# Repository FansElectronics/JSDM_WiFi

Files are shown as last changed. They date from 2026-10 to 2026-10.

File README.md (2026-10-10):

# Jadwal Sholat Dot Matrix (JSDM) P10 dengan ESP8266 & ESP32

Firmware display Jadwal Waktu Sholat dengan tampilan Panel P10 Dot Matrix Display (DMD) menggunakan mikrokontroler ESP8266 dan ESP32. Project ini dirancang untuk menjalankan sebuah sistem dan perhitungan jadwal sholat di Indonesia. Sudah didukung dengan pengaturan dengan aplikasi Android yang dapat di download di: https://play.google.com/store/apps/details?id=com.fanselectronics.jsdm&hl=id

## Spesifikasi Firmware ⚙️:
- Mendukung Mikrokontroler ESP8266 dan ESP32
- Mendukung RTC DS3231
- Mendukung Panel P10 Single Color
- Menggunakan catu daya 5V (disesuaikan panel)
- Pengaturan melalui aplikasi Android
- 1 baris Panel x Maksimal 6 kolom Panel (disesuaikan lisensi)

## Fitur yang tersedia ✅:
- Animasi Jadwal Waktu Sholat (tersida beberapa model animasi sesuai pilihan jumlah panel)
- Animasi pesan running text (custom melalui aplikasi android)
- Logo Allah & Muhammad (tersida beberapa model logo)
- Sleep Mode saat malam hari tidak terpakai
- Kalendar Masehi, Hijriah, dan Jawa (Pasaran, Wuku, dan Tahun menurut kalendar Agungan)
- Alarm / Alert waktu Adzan
- Waktu hitung mundur Qobliyah setelah Adzan dan tunggu Iqomah
- Pengaturan waktu Iqomah setiap sholat
- Sleep Mode waktu sholat
- Sleep Mode waktu khotbah Jum'at
- Upload **license.json** melalui aplikasi android
- Update firmware On the Air (OTA), update firmware lebih mudah via internet

_**Catatan:** fitur dan animasi akan selalu diupdate, anda bisa update firmware terbaru dengan mudah melalui fitur OTA di aplikasi android._

## Default SSID + Password
```
    SSID: JSDM WiFi Android
    PASS: fanselectronics
```

## Mengapa dimulai dari versi 3?

Sebelumnya project ini bersifat private saja dengan membuka firmware dan mengimplementasikan sistem lisensi, siapapun dapat membuat sendiri dan hanya tinggal membeli lisensi firmwarenya saja dengan mudah dan murah.

## Bagaimana Sistem Lisensinya?

Kami mengimplementasikan sistem lisensi terenkripsi berbasis **Identifikasi Hardware** unik. Setiap ESP8266 dan ESP32 memiliki ID Unik yang tidak dapat ditukarkan, jadi pembeli tinggal mengirimkan **Device ID** yang tersedia pada menu activation aplikasi setelah aplikasi terhubung ke perangkat dan kami akan mengirimkan file **license.json** yang dapat diupload ke perangkat melalui fitur **Activation** di aplikasi Android.

Menengapa lisensi harus berbayar? tentunya kami membutuhkan dana untuk keperluan riset dan biaya hidup, permintaan ini juga memberikan kami semangat untuk terus memelihara dan perbarui fitur-fitur pada firmware dari JSDM WiFi Android ini. Sehingga mohon pengertiannya.

**Adapun Harga Lisensi dibedakan berdasarkan jumlah panel sebagai berikut 🏷️:**
- 1 Panel : Rp. 25.000
- 2 Panel : Rp. 35.000
- 3 Panel : Rp. 45.000
- 4 Panel : Rp. 55.000
- 5 Panel : Rp. 65.000
- 6 Panel : Rp. 75.000

**Syarat dan Ketentuan Lisensi 📜:** 
- Lisensi berlaku untuk 1 chip ESP866 atau ESP32, karena mengikat berdasarkan chip.
- Lisensi berlaku untuk 1 jenis jumlah panel (setelah lisensi dikirim tidak bisa ganti ukuran)
- Apabila terjadi kerusakan chip kami bisa mengganti lisensi dengan syarat mengirim chip yang rusak kepada kami guna mengihindari penipuan chip rusak. Kami akan kirim lisensi baru dengan DEVICE ID chip yang baru. kalau tidak bisa mengirimkan chip yang rusak bisa beli lisensi baru kembali.
- Kami tidak menerima garansi lisensi apabila pembelian tidak melalui kami secara langsung (beli di pihak ke-3).

## Sistem pembayaran 💵

Kami memberikan 2 sistem pembayaran dimana sistem donasi dan pembayaran sesuai harga tertera. Anda dapat menggunakan sistem donasi apabila ingin memberikan support kepada kami melebihi harga lisensi yang ada.
- Pembelian dan Bantuan: https://wa.me/6281803750001
- Donasi: https://saweria.co/fanselectronics

## Bagaimana Upload Firmwarenya❓
Kami telah menyediakan tool untuk upload / flash chip ES8266 dan ESP32 yang memudahkan siapapun untuk membuat project ini secara mandiri. Berikut url tool JSDM WiFi Flasher:
- Flasher Tools: https://app.fanselectronics.com/flasher/JSDM/
- Tutorialnya bisa baca di [FLASHER.md](FLASHER.md)

## Skematik dan PCB 💾
Semua file Skematik dan PCB saya sediakan gratis di dalam repository ini dalam bentuk desain apliksi EAGLE PCB hingga export PDF. Sesuaikan dengan board yang anda gunakan atau anda bisa mengkustomisasi sesuai dengan keinginan anda dengan panduan pin I/O yang sudah disediakan.

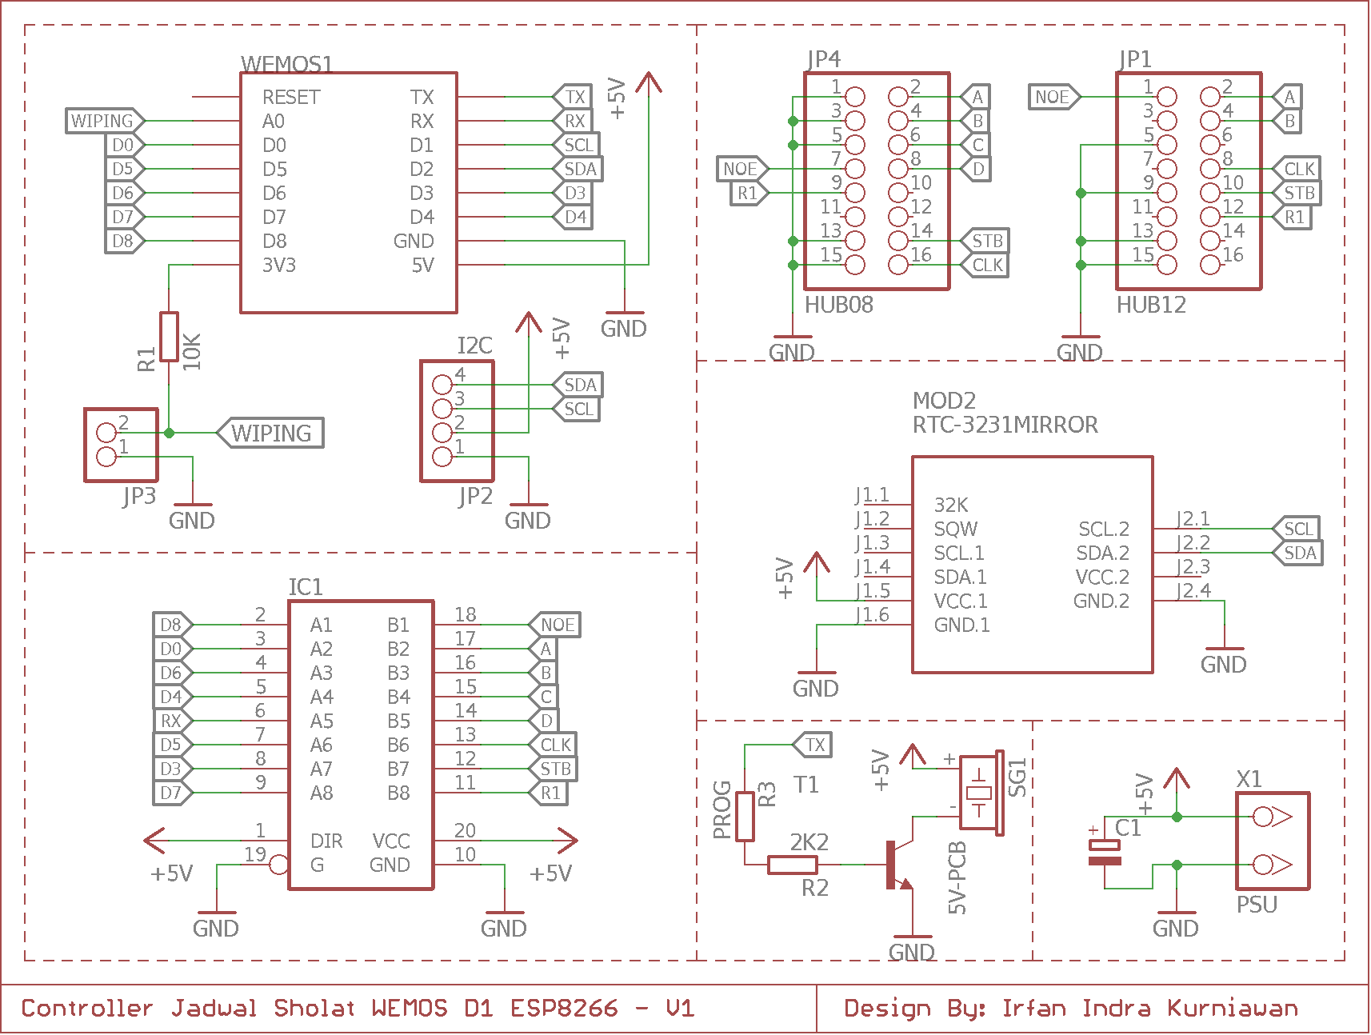
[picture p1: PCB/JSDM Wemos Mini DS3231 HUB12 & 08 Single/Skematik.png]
Skematik JSDM ESP8266 Wemos D1 Mini

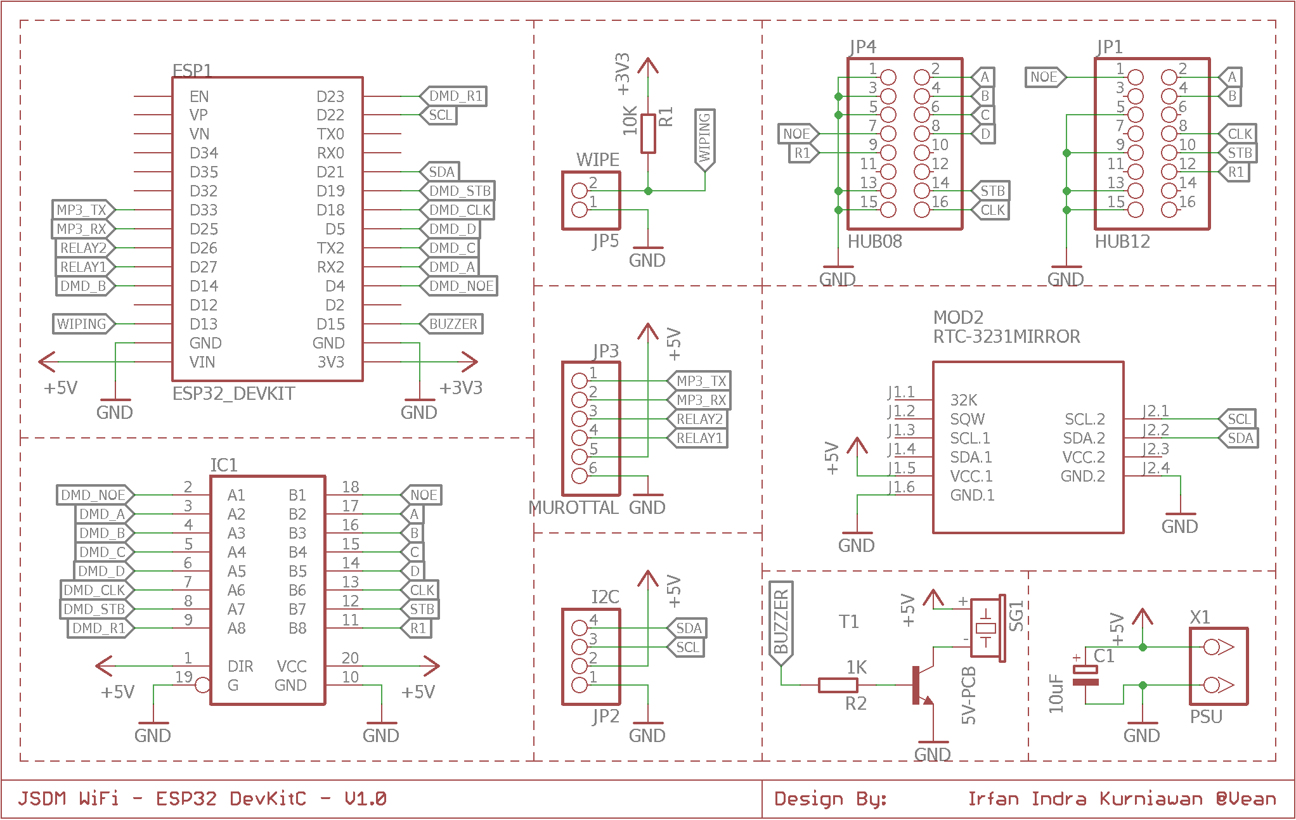
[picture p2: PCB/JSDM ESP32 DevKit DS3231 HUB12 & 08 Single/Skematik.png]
Skematik JSDM ESP32 DevKit


## Tutorial & Video 🎥

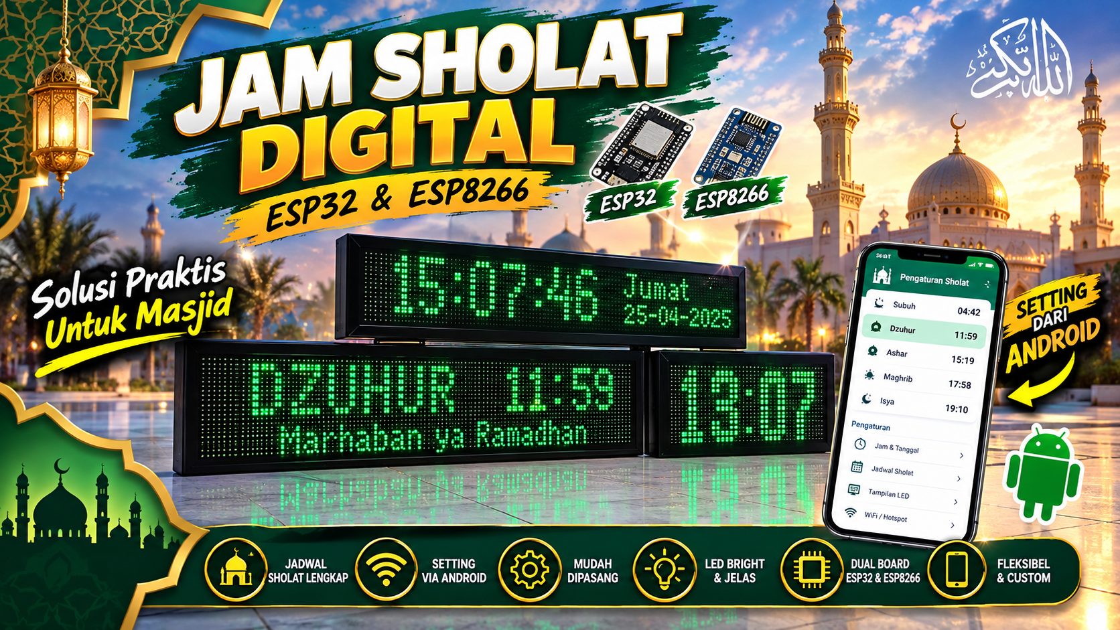
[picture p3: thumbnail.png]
Tutorial JSDM WiFi (https://www.youtube.com/watch?v=nER4bm2BxC0)


## Terima Kasih Kepada 🤲
- Allah Subhanahu Wa Ta'ala
- Arduino.cc
- GitHub
- Kontributor
- Semua orang yang mentraktir saya kopi

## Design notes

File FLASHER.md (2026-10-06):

# Panduan Singkat Flash ESP32 & ESP8266

Gunakan **Google Chrome** atau **Microsoft Edge**.

## Langkah Flashing

1. **Colokkan ESP** ke komputer menggunakan kabel USB Data.

2. Buka ESP Flasher:
   **https://app.fanselectronics.com/flasher/JSDM/**

3. **Masuk ke mode flash:**

   * **ESP32:** tekan dan tahan tombol **BOOT**.
   * **ESP8266:** tekan dan tahan tombol **FLASH**. Jika perlu, tekan **RESET/RST** sekali.

4. Klik **Connect** pada ESP Flasher.

5. Pilih **Serial Port** ESP yang terhubung, lalu klik **Connect**.

6. Setelah ESP berhasil terdeteksi, **lepaskan tombol BOOT/FLASH**.

7. Pilih firmware yang sesuai dengan board:

   * ESP32 → firmware ESP32
   * ESP8266 → firmware ESP8266

8. Jika diperlukan, klik **Erase Flash** dan tunggu sampai selesai.

9. Klik **Flash** untuk memulai proses flashing.

10. **Jangan mencabut USB atau menekan tombol RESET selama proses flashing.** Tunggu sampai proses selesai.

11. Setelah selesai, ESP akan restart dan menjalankan firmware yang baru.

### Jika Gagal Terhubung

Coba ulangi proses dari awal:

**Cabut USB → colok kembali → tahan BOOT/FLASH → Connect → pilih Serial Port → tunggu terdeteksi → lepaskan BOOT/FLASH → Flash.**

Pastikan menggunakan kabel USB **Data** dan browser **Chrome/Edge**.

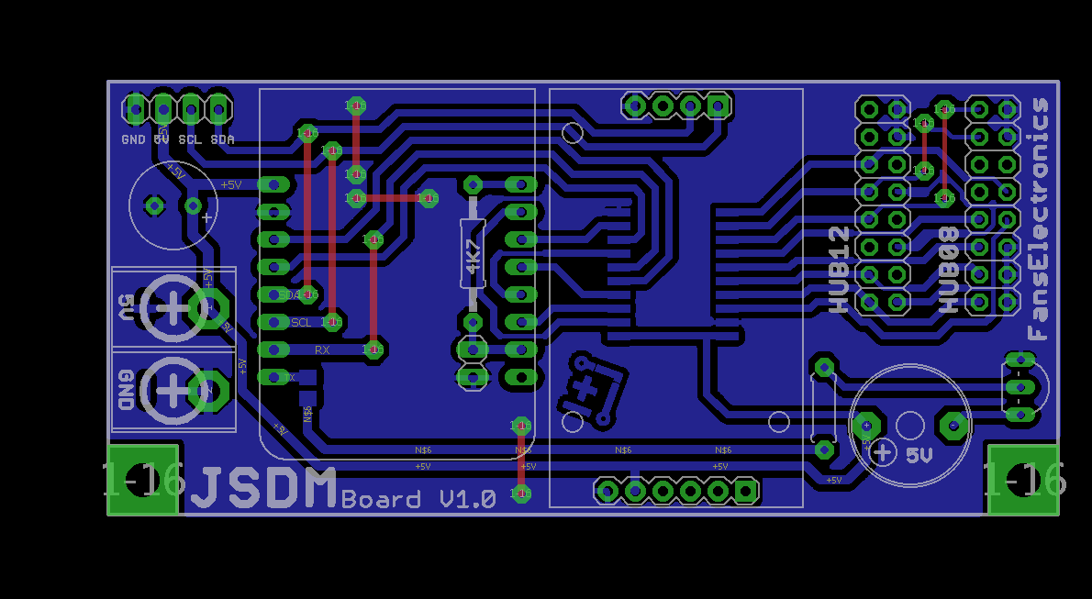
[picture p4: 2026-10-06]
PCB/JSDM Wemos Mini DS3231 HUB12 & 08 Single/Board.png

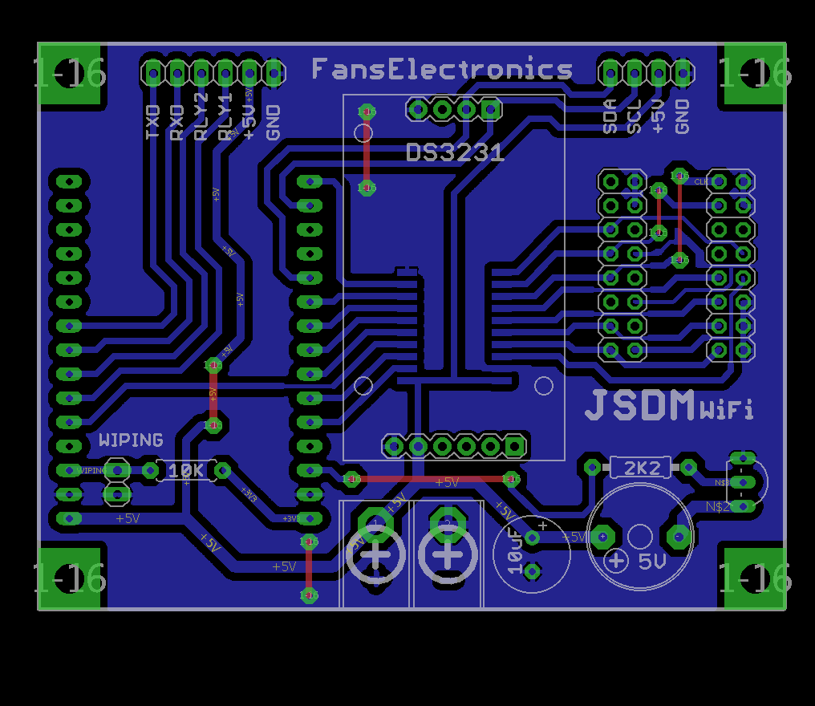
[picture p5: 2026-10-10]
PCB/JSDM ESP32 DevKit DS3231 HUB12 & 08 Single/Board.png

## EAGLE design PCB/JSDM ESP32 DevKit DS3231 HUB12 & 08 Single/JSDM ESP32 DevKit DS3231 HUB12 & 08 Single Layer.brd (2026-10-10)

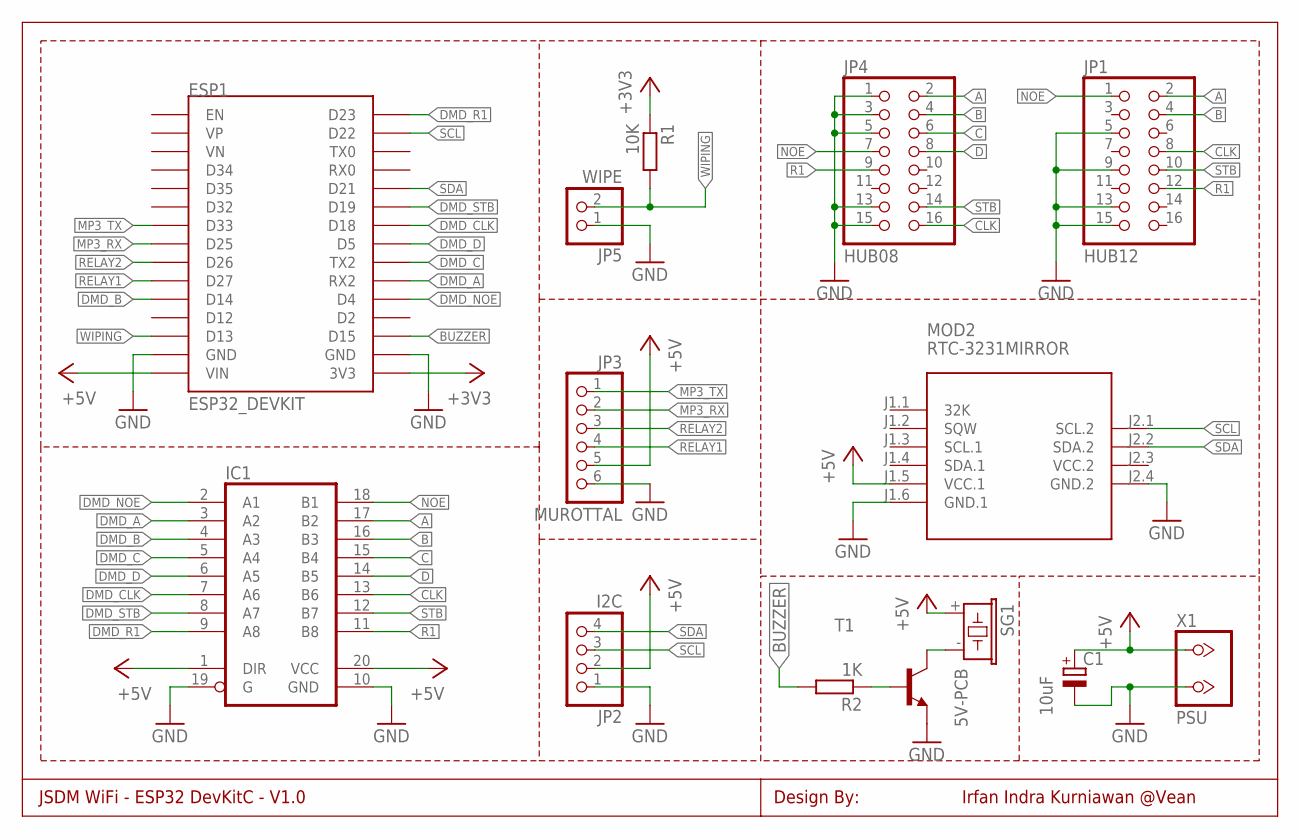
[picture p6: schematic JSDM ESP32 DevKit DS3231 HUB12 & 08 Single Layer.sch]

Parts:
C1: 10uF; E3,5-8
ESP1: ESP32_DEVKIT
IC1: 74245SMD; SO20
JP1: HUB12; 2X08
JP2: I2C; 1X04
JP3: MUROTTAL; 1X06
JP4: HUB08; 2X08
JP5: WIPE; 1X02
MOD2: RTC-3231MIRROR; RTC-DS3231-MIRROR
R1: 10K; 0207/7
R2: 1K; 0207/10
SG1: 5V-PCB; 5V
T1: BC317-NPN-TO92-EBC; TO92-EBC
X1: PSU; TB2

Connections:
+3V3: ESP1.3V3, R1.1
+5V: C1.+, ESP1.VIN, IC1.1 (DIR), IC1.20 (VCC), JP2.2, JP3.5, MOD2.J1.5 (VCC.1), SG1.+ (1), X1.1
A: IC1.17 (B2), JP1.2, JP4.2
B: IC1.16 (B3), JP1.4, JP4.4
BUZZER: ESP1.D15, R2.2
C: IC1.15 (B4), JP4.6
CLK: IC1.13 (B6), JP1.8, JP4.16
D: IC1.14 (B5), JP4.8
DMD_A: ESP1.RX2, IC1.3 (A2)
DMD_B: ESP1.D14, IC1.4 (A3)
DMD_C: ESP1.TX2, IC1.5 (A4)
DMD_CLK: ESP1.D18, IC1.7 (A6)
DMD_D: ESP1.D5, IC1.6 (A5)
DMD_NOE: ESP1.D4, IC1.2 (A1)
DMD_R1: ESP1.D23, IC1.9 (A8)
DMD_STB: ESP1.D19, IC1.8 (A7)
GND: C1.-, ESP1.GND@1 (GND), ESP1.GND@2 (GND), IC1.10 (GND), IC1.19 (G), JP1.5, JP1.9, JP1.13, JP1.15, JP2.1, JP3.6, JP4.1, JP4.3, JP4.5, JP4.13, JP4.15, JP5.1, MOD2.J1.6 (GND.1), MOD2.J2.4 (GND.2), T1.E, X1.2
MP3_RX: ESP1.D25, JP3.2
MP3_TX: ESP1.D33, JP3.1
unnamed: SG1.- (2), T1.C
unnamed: R2.1, T1.B
NOE: IC1.18 (B1), JP1.1, JP4.7
R1: IC1.11 (B8), JP1.12, JP4.9
RELAY1: ESP1.D27, JP3.4
RELAY2: ESP1.D26, JP3.3
SCL: ESP1.D22, JP2.3, MOD2.J2.1 (SCL.2)
SDA: ESP1.D21, JP2.4, MOD2.J2.2 (SDA.2)
STB: IC1.12 (B7), JP1.10, JP4.14
VCC.2: MOD2.J2.3 (VCC.2)
WIPING: ESP1.D13, JP5.2, R1.2

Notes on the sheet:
JSDM WiFi - ESP32 DevKitC - V1.0
Irfan Indra Kurniawan @Vean
Design By:

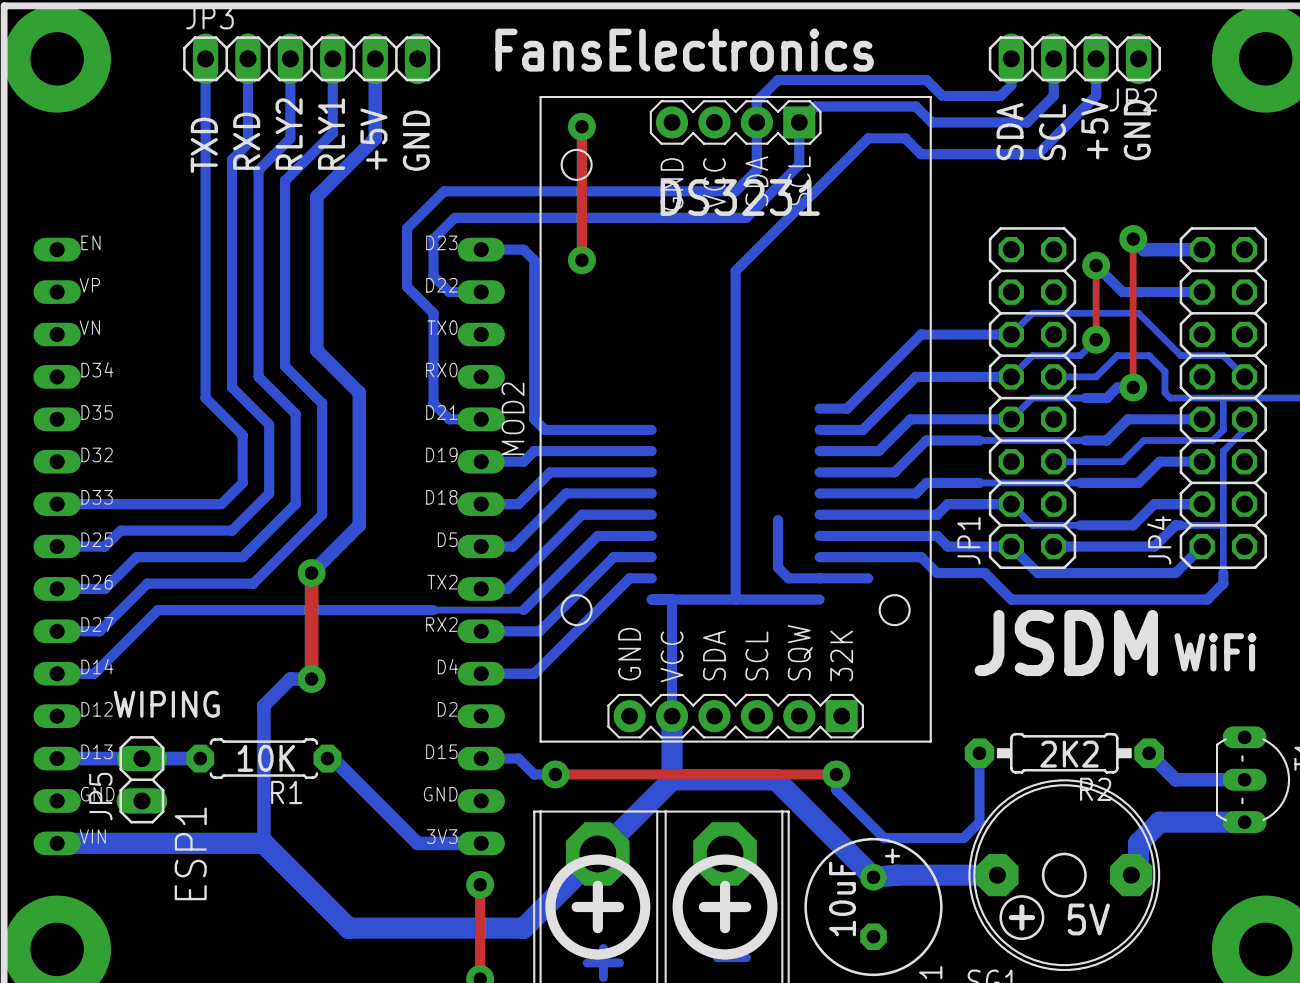
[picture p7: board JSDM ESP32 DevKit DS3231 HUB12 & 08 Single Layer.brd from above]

Board: 2 copper layers, 14 parts (1 on the bottom side), 29 nets.

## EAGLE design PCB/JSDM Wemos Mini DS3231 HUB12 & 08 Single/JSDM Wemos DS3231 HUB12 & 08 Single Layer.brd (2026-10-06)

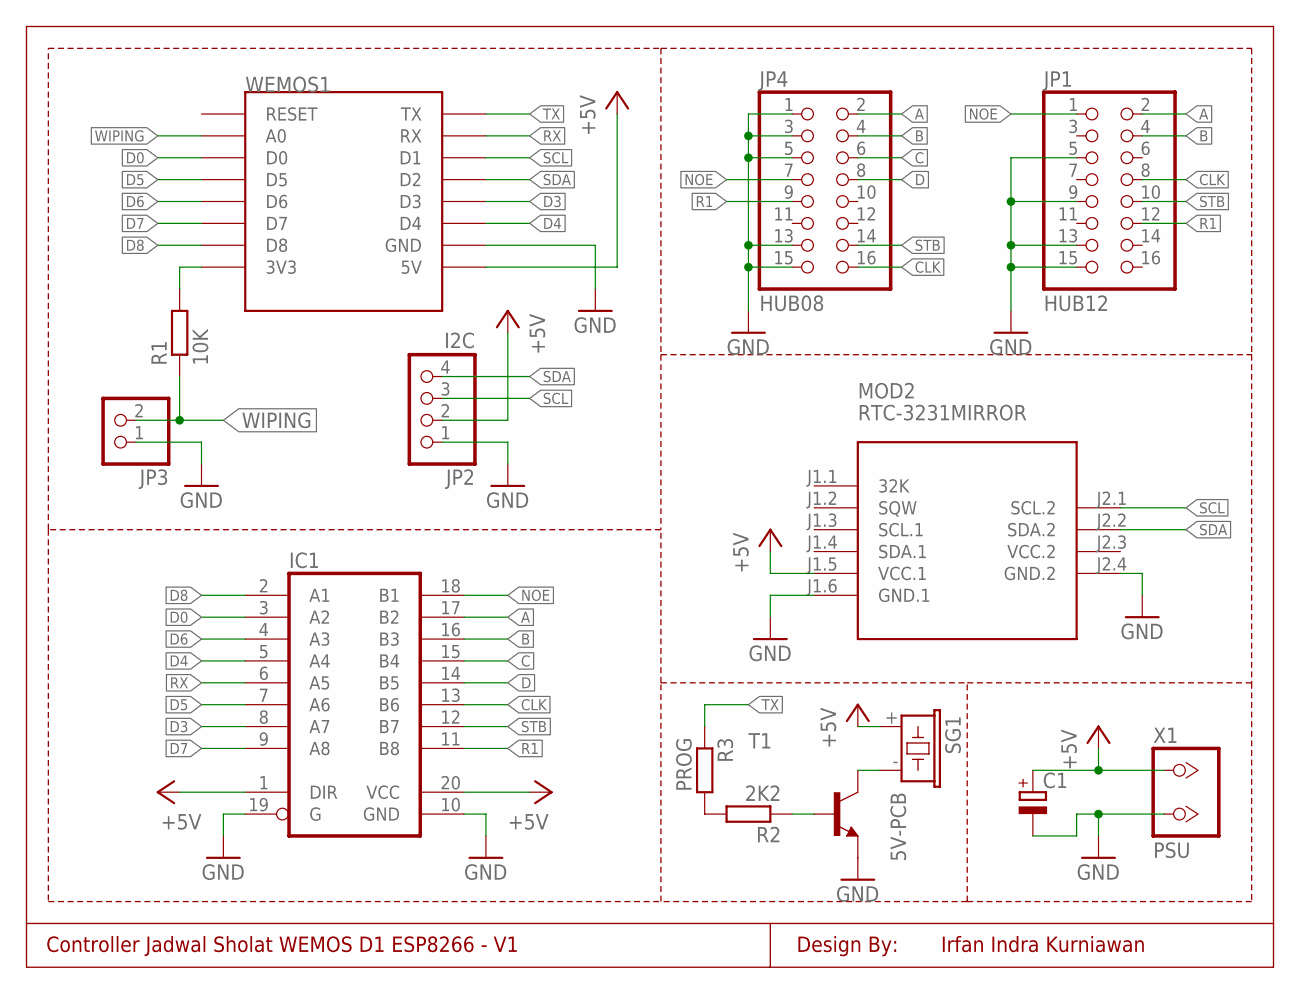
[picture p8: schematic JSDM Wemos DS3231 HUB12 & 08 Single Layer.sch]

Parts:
C1: CPOL-EUE3.5-8; E3,5-8
IC1: 74245SMD; SO20
JP1: HUB12; 2X08
JP2: I2C; 1X04
JP3: PINHD-1X2; 1X02
JP4: HUB08; 2X08
MOD2: RTC-3231MIRROR; RTC-DS3231-MIRROR
R1: 10K; 0207/12
R2: 2K2; 0207/7
R3: PROG; M0805
SG1: 5V-PCB; 5V
T1: BC317-NPN-TO92-EBC; TO92-EBC
WEMOS1: WEMOS-D1-MINI
X1: PSU; TB2

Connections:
+5V: C1.+, IC1.1 (DIR), IC1.20 (VCC), JP2.2, MOD2.J1.5 (VCC.1), SG1.+ (1), WEMOS1.5V, X1.1
A: IC1.17 (B2), JP1.2, JP4.2
B: IC1.16 (B3), JP1.4, JP4.4
C: IC1.15 (B4), JP4.6
CLK: IC1.13 (B6), JP1.8, JP4.16
D: IC1.14 (B5), JP4.8
D0: IC1.3 (A2), WEMOS1.D0
D3: IC1.8 (A7), WEMOS1.D3
D4: IC1.5 (A4), WEMOS1.D4
D5: IC1.7 (A6), WEMOS1.D5
D6: IC1.4 (A3), WEMOS1.D6
D7: IC1.9 (A8), WEMOS1.D7
D8: IC1.2 (A1), WEMOS1.D8
GND: C1.-, IC1.10 (GND), IC1.19 (G), JP1.5, JP1.9, JP1.13, JP1.15, JP2.1, JP3.1, JP4.1, JP4.3, JP4.5, JP4.13, JP4.15, MOD2.J1.6 (GND.1), MOD2.J2.4 (GND.2), T1.E, WEMOS1.GND, X1.2
unnamed: R1.2, WEMOS1.3V3
unnamed: SG1.- (2), T1.C
unnamed: R2.1, T1.B
unnamed: R2.2, R3.2
NOE: IC1.18 (B1), JP1.1, JP4.7
R1: IC1.11 (B8), JP1.12, JP4.9
RX: IC1.6 (A5), WEMOS1.RX
SCL: JP2.3, MOD2.J2.1 (SCL.2), WEMOS1.D1
SDA: JP2.4, MOD2.J2.2 (SDA.2), WEMOS1.D2
STB: IC1.12 (B7), JP1.10, JP4.14
TX: R3.1, WEMOS1.TX
VCC.2: MOD2.J2.3 (VCC.2)
WIPING: JP3.2, R1.1, WEMOS1.A0

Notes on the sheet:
Controller Jadwal Sholat WEMOS D1 ESP8266 - V1
Irfan Indra Kurniawan
Design By:

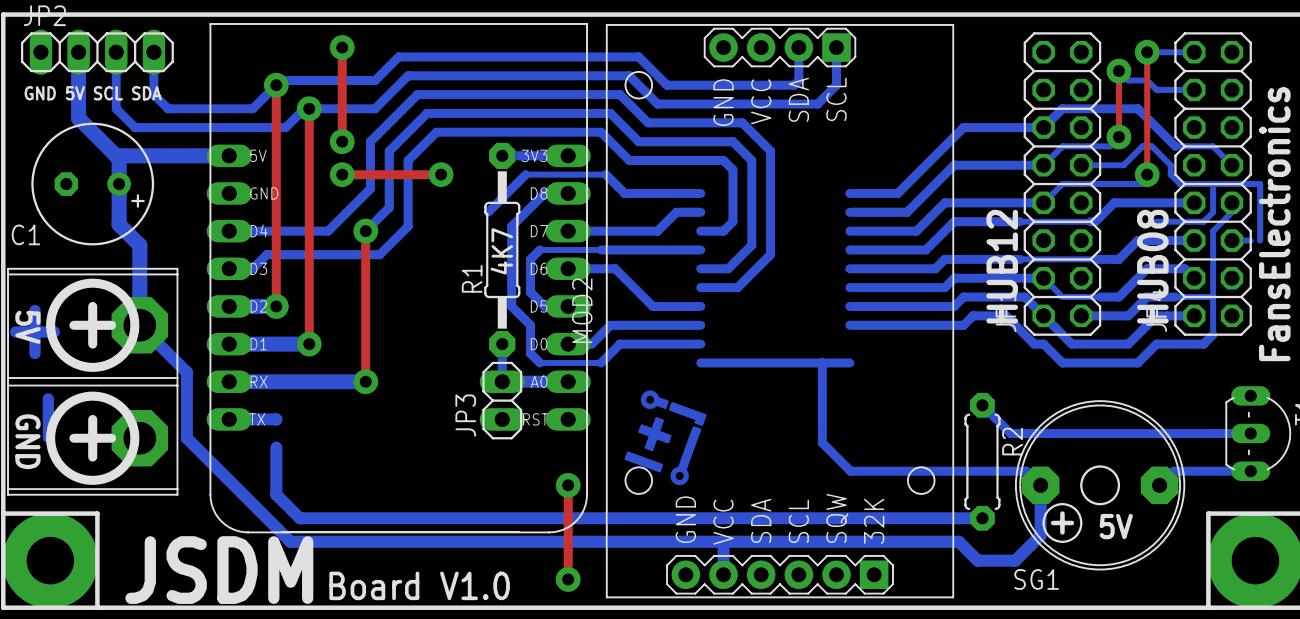
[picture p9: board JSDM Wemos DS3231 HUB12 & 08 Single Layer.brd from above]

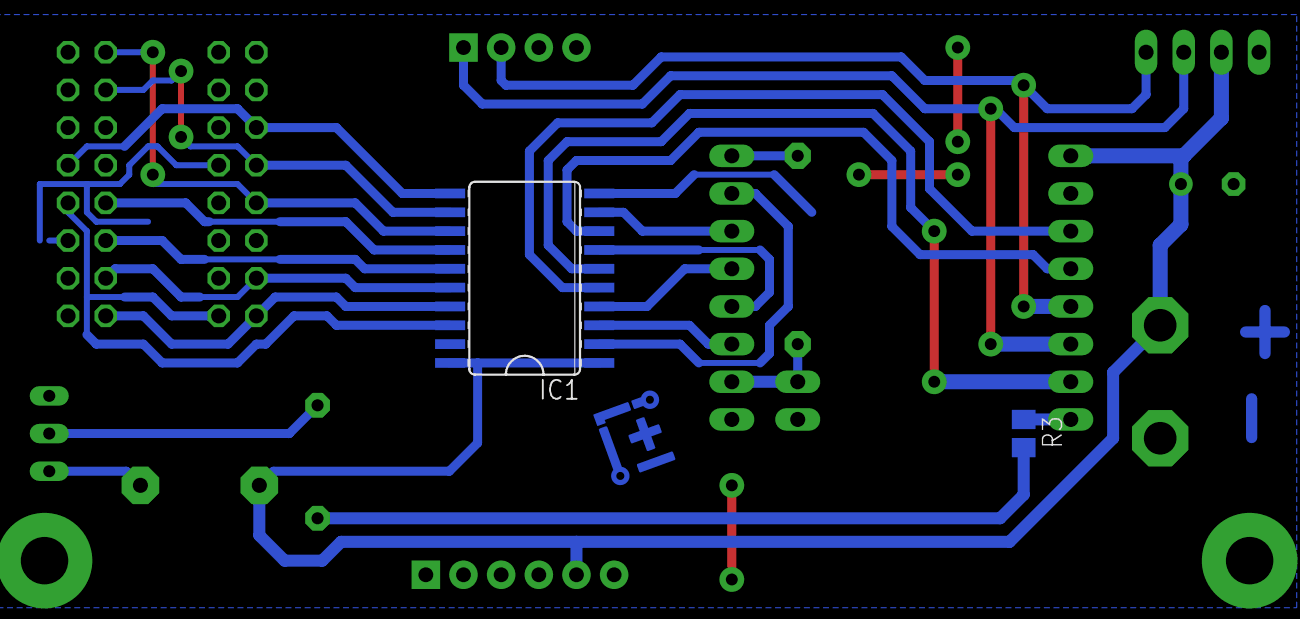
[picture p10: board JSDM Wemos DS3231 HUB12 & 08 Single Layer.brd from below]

Board: 2 copper layers, 14 parts (2 on the bottom side), 26 nets.

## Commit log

2026-10-03 PCB Wemos D1 Mini
    - Single Layer
    - ESP8266 Wemos D1 Mini
    - RTC DS3231
    - Buzzer Aktif 5V + Transistor S9013
    [JSDM Wemos DS3231 Single Layer.brd, JSDM Wemos DS3231 Single Layer.sch]
2026-10-06 Penyesuain Harga 🙏
2026-10-06 Update Skematik ESP8266
    [JSDM Wemos DS3231 Single Layer.brd, JSDM Wemos DS3231 Single Layer.sch]
2026-10-10 Tambah Driver CH340 v4.0
    Driver CH340 dari https://sparks.gogo.co.nz/ch340.html
2026-10-10 Tambah Driver CP210x Universal Windows v11.6.0
    Package version: 11.6.0
    Release date: 2026-09-15
    Source: https://www.silabs.com/software-and-tools/usb-to-uart-bridge-vcp-drivers?tab=downloads
2026-10-10 Rename PCB Wemos D1
    [JSDM Wemos DS3231 HUB12 & 08 Single Layer.brd, JSDM Wemos DS3231 HUB12 & 08 Single Layer.sch]
2026-10-10 PCB ESP32 DevKit
    Desain Eagle PCB dan Skematik versi ESP32 Devkit C
    - 1 HUB12
    - 1 HUB08
    - DS3231
    - Buzzer 5V
    - IC Buffer Voltage Logic 74HC245
    [JSDM ESP32 DevKit DS3231 HUB12 & 08 Single Layer.brd, JSDM ESP32 DevKit DS3231 HUB12 & 08 Single Layer.sch]
2026-10-10 Tambah Skematik ESP32
2026-10-24 Update PCB Terbaru
    Penambahan Desain PCB baru
    Update Harga Penyesuaikan Auto Murottal
